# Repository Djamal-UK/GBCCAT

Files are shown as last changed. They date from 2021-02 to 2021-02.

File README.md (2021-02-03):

# GBCCAT
GBCCAT - Gameboy Color Emulator based on GNUBOY,
still in development, used hardware is ESP32 WROVER chip, ST7789 1.3" LCD 240*240px,
loading games from microSD card, emulator has been controlled by PS2 (USB) keyboard.

Image description

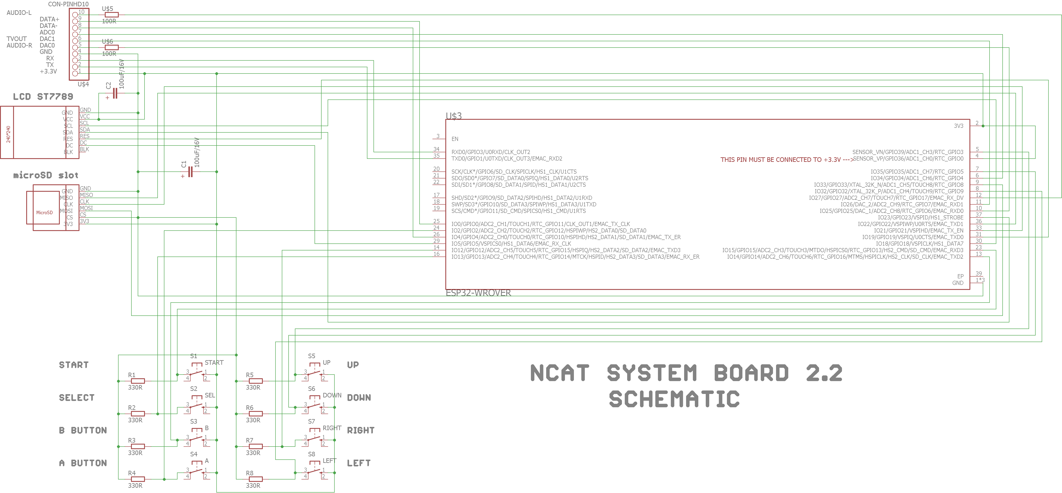
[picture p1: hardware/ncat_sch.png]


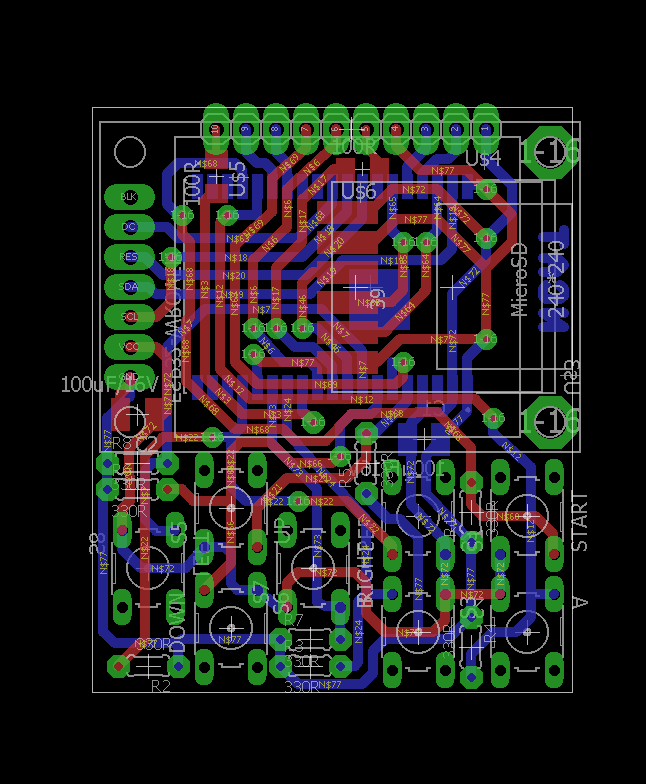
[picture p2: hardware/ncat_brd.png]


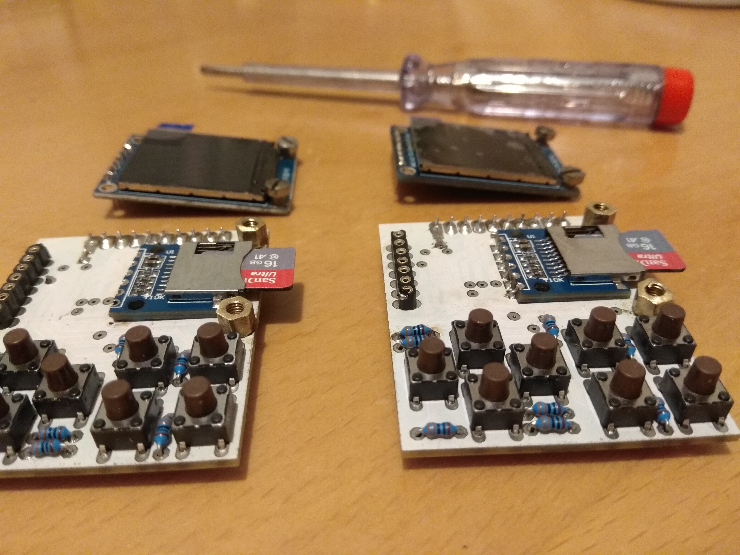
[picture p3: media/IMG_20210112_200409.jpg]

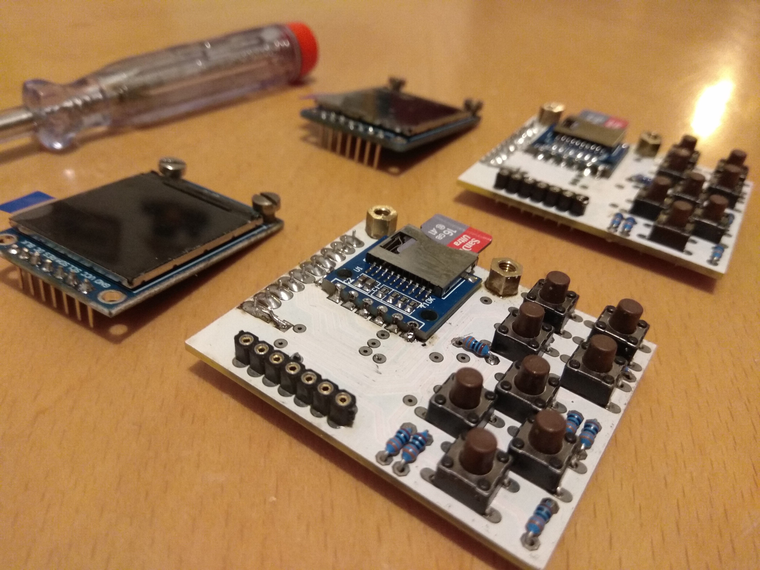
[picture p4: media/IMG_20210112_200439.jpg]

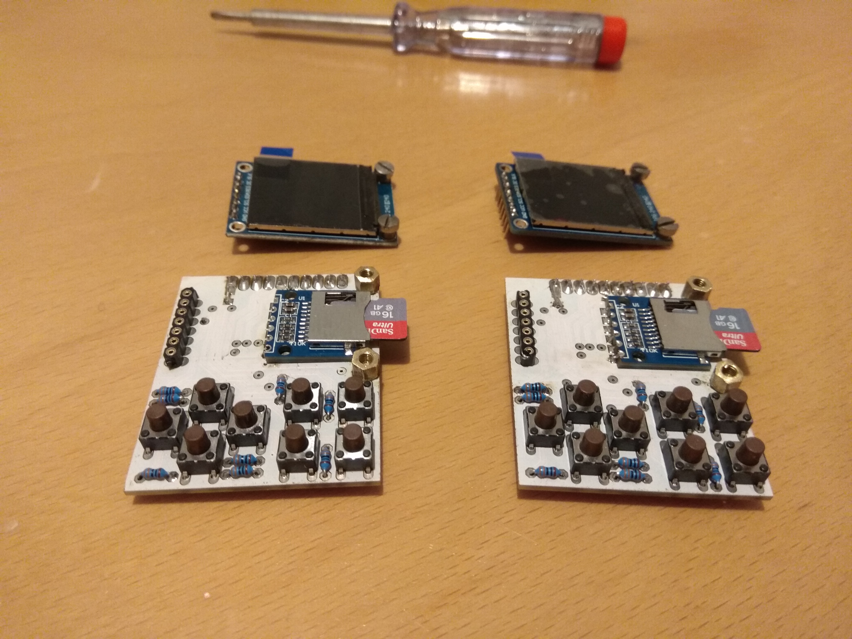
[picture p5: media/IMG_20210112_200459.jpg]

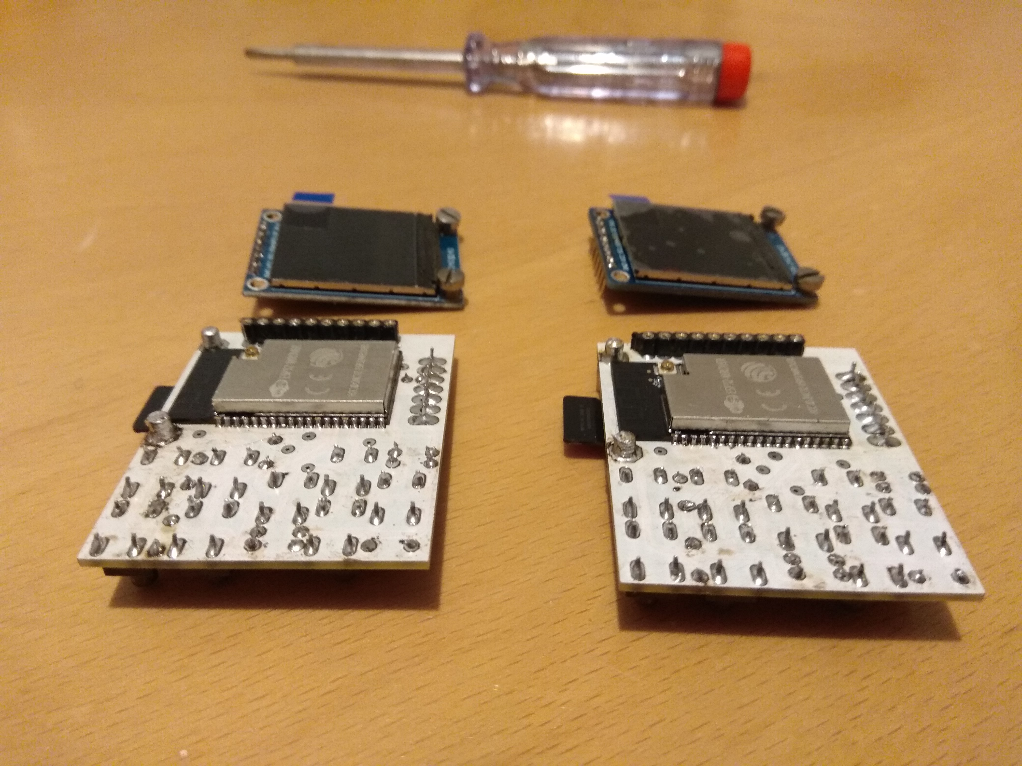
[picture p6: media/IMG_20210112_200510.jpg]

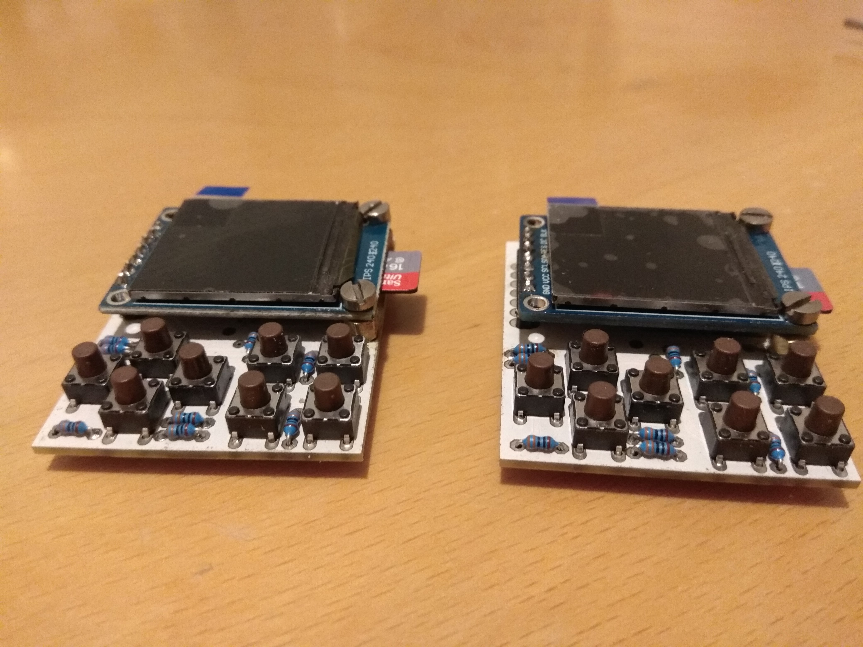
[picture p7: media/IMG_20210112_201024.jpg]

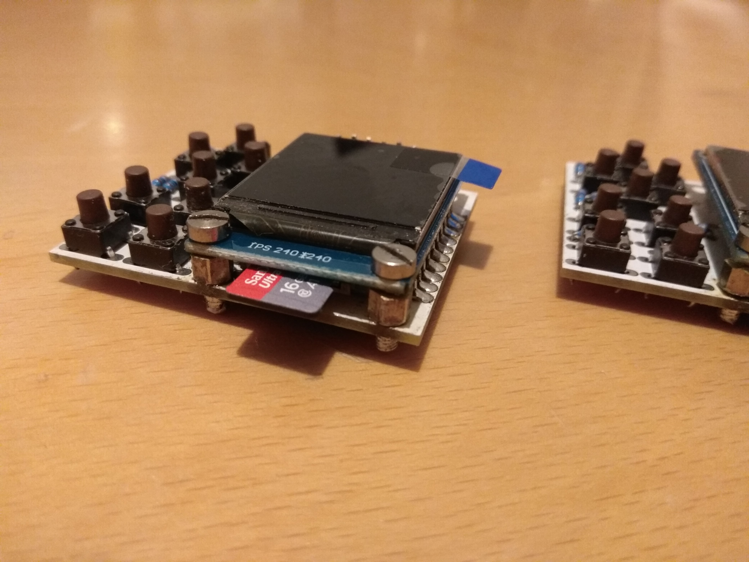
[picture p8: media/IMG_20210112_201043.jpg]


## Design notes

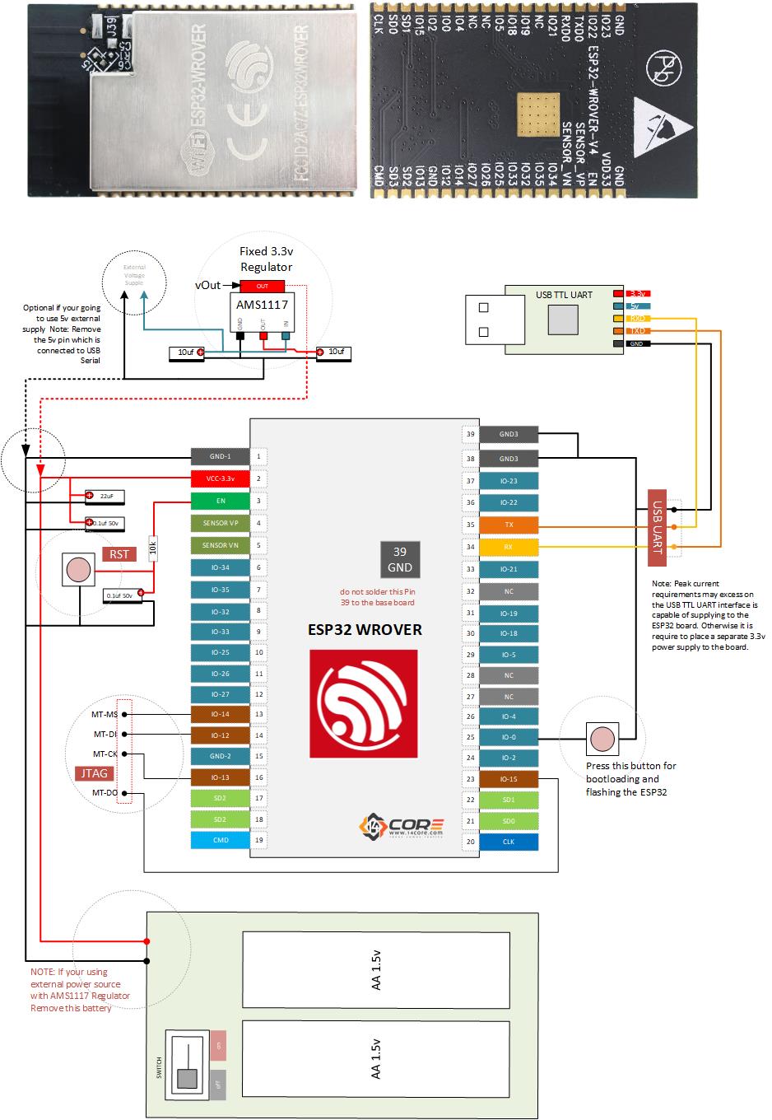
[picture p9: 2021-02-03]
media/Flashing-esp32-wroom-esp32-wrover-flash-download-tool-diagram-schematics.jpg

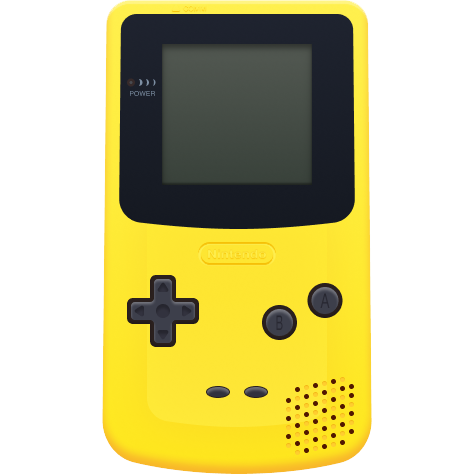
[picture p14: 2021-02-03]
nmcndnhlndv.png

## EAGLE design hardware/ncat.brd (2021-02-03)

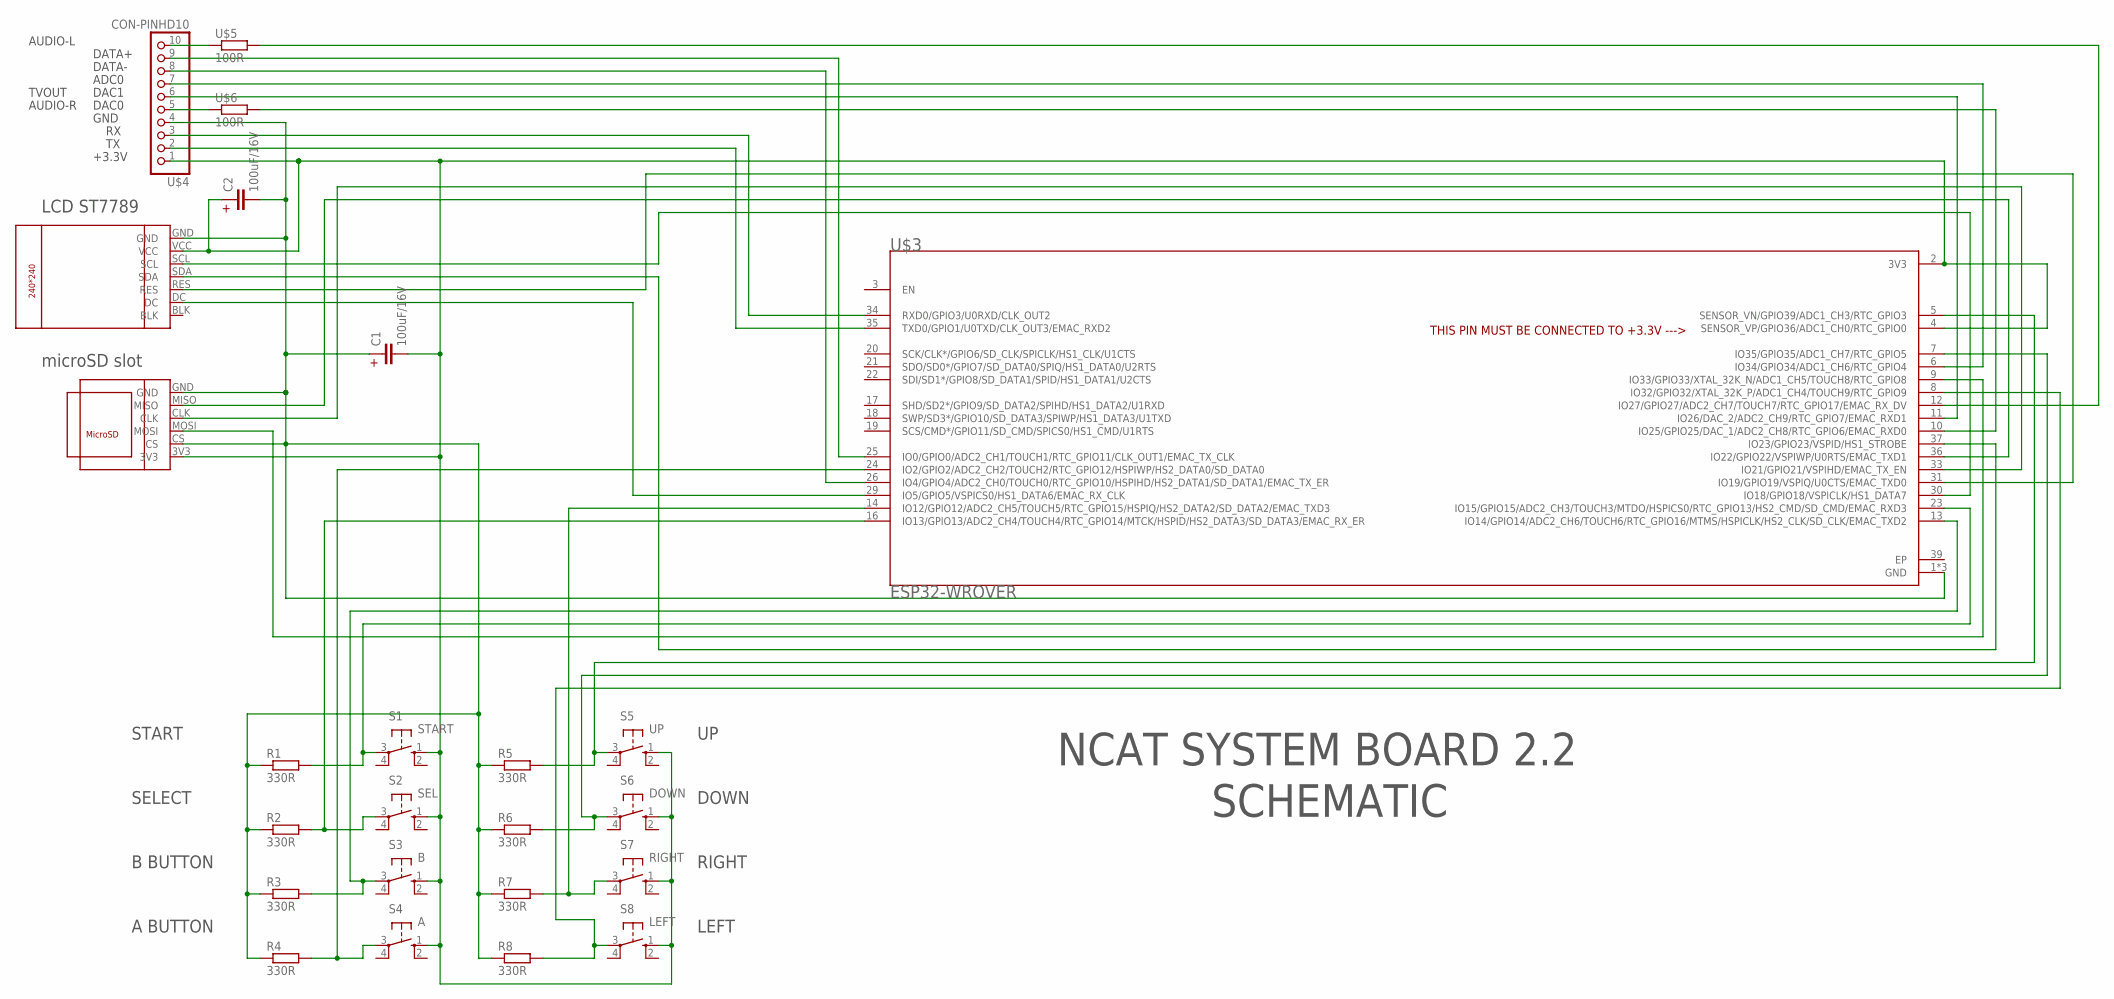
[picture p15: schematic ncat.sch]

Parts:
C1, C2: 100uF/16V; C1210
R1, R2, R3, R4, R5, R6, R7, R8: 330R; R0204/5H
S1: START; B3F-10XX
S2: SEL; B3F-10XX
S3: B; B3F-10XX
S4: A; B3F-10XX
S5: UP; B3F-10XX
S6: DOWN; B3F-10XX
S7: RIGHT; B3F-10XX
S8: LEFT; B3F-10XX
U$1: MICROSD-CARD-MODULESMD; MICROSD-CARD-MODULE-SMD
U$3: ESP32-WROVER; XCVR-ESP32-WROVER
U$4: CON-PINHD10; PIN1X10
U$5, U$6: 100R; R1206/SMD
U$7: LCD-ST7789-1.3INCH

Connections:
EP: U$3.39 (EP)
unnamed: U$3.35 (TXD0/GPIO1/U0TXD/CLK_OUT3/EMAC_RXD2), U$4.2
unnamed: U$3.34 (RXD0/GPIO3/U0RXD/CLK_OUT2), U$4.3
unnamed: U$3.12 (IO27/GPIO27/ADC2_CH7/TOUCH7/RTC_GPIO17/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), U$5.2
unnamed: U$4.5, U$6.1
unnamed: U$4.10, U$5.1
unnamed: U$3.11 (IO26/DAC_2/ADC2_CH9/RTC_GPIO7/EMAC_RXD1), U$4.6
unnamed: R8.2, S8.3, U$3.8 (IO32/GPIO32/XTAL_32K_P/ADC1_CH4/TOUCH9/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)
unnamed: R4.2, S4.3, U$3.24 (IO2/GPIO2/ADC2_CH2/TOUCH2/RTC_GPIO12/HS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)
unnamed: U$3.10 (IO25/GPIO25/DAC_1/ADC2_CH8/RTC_GPIO6/EM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), U$6.2
unnamed: U$3.30 (IO18/GPIO18/VSPICLK/HS1_DATA7), U$7.SCL
unnamed: U$3.37 (IO23/GPIO23/VSPID/HS1_STROBE), U$7.SDA
unnamed: U$3.31 (IO19/GPIO19/VSPIQ/U0CTS/EMAC_TXD0), U$7.RES
unnamed: R5.2, S5.3, U$3.5 (SENSOR_VN/GPIO39/ADC1_CH3/RTC_GPIO3)
unnamed: R2.2, S2.3, U$3.16 (IO13/GPIO13/ADC2_CH4/TOUCH4/RTC_GPIO14/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)
unnamed: R3.2, S3.3, U$3.13 (IO14/GPIO14/ADC2_CH6/TOUCH6/RTC_GPIO16/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)
unnamed: U$1.MOSI, U$3.9 (IO33/GPIO33/XTAL_32K_N/ADC1_CH5/TOUCH8/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)
unnamed: U$3.29 (IO5/GPIO5/VSPICS0/HS1_DATA6/EMAC_RX_CLK), U$7.DC
unnamed: U$1.MISO, U$3.36 (IO22/GPIO22/VSPIWP/U0RTS/EMAC_TXD1)
unnamed: U$1.CLK, U$3.33 (IO21/GPIO21/VSPIHD/EMAC_TX_EN)
unnamed: R6.2, S6.3, U$3.7 (IO35/GPIO35/ADC1_CH7/RTC_GPIO5)
unnamed: R1.2, S1.3, U$3.23 (IO15/GPIO15/ADC2_CH3/TOUCH3/MTDO/HSPICS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)
unnamed: U$3.6 (IO34/GPIO34/ADC1_CH6/RTC_GPIO4), U$4.7
unnamed: U$3.26 (IO4/GPIO4/ADC2_CH0/TOUCH0/RTC_GPIO10/HS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), U$4.8
unnamed: U$3.25 (IO0/GPIO0/ADC2_CH1/TOUCH1/RTC_GPIO11/CL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), U$4.9
unnamed: C1.2, C2.1, S1.1 (S), S2.1 (S), S3.1 (S), S4.1 (S), S5.1 (S), S6.1 (S), S7.1 (S), S8.1 (S), U$1.3V3, U$3.2 (3V3), U$3.4 (SENSOR_VP/GPIO36/ADC1_CH0/RTC_GPIO0), U$4.1, U$7.VCC
unnamed: R7.2, S7.3, U$3.14 (IO12/GPIO12/ADC2_CH5/TOUCH5/RTC_GPIO15/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)
unnamed: C1.1, C2.2, R1.1, R2.1, R3.1, R4.1, R5.1, R6.1, R7.1, R8.1, U$1.CS, U$1.GND, U$3.1 (GND), U$3.15 (GND), U$3.38 (GND), U$4.4, U$7.GND

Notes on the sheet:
LCD ST7789
microSD slot
START
SELECT
A BUTTON
B BUTTON
DOWN
RIGHT
LEFT
GND
DAC1
DAC0
ADC0
DATA+
DATA-
+3.3V
SCHEMATIC
TVOUT
AUDIO-L
AUDIO-R
NCAT SYSTEM BOARD 2.2
THIS PIN MUST BE CONNECTED TO +3.3V --->

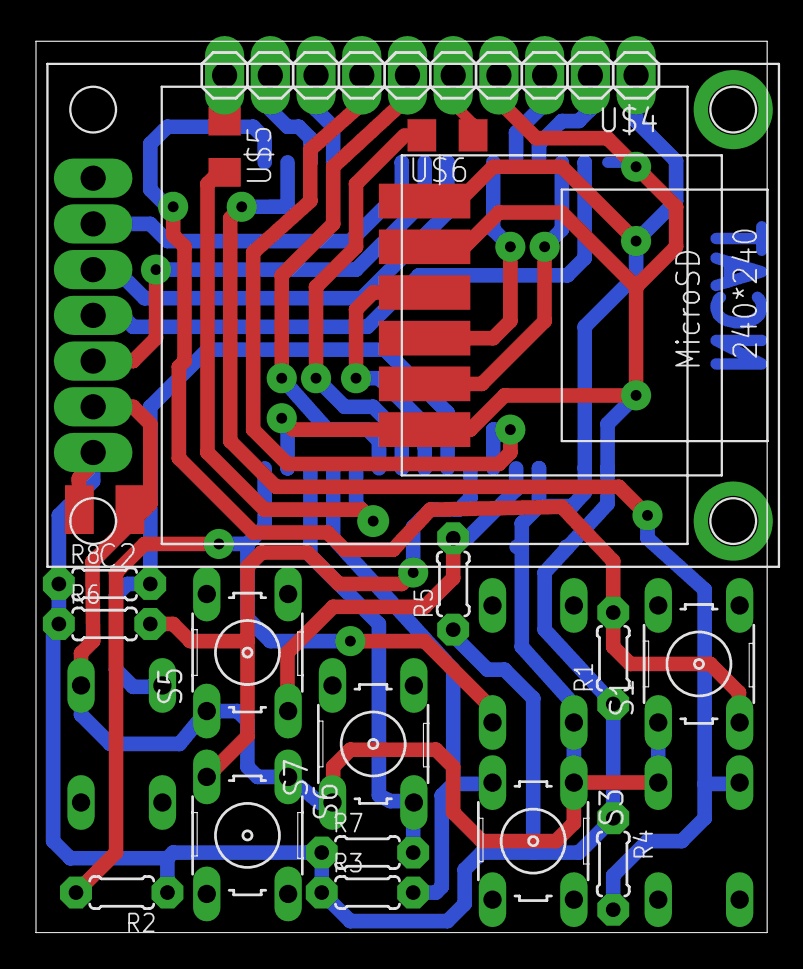
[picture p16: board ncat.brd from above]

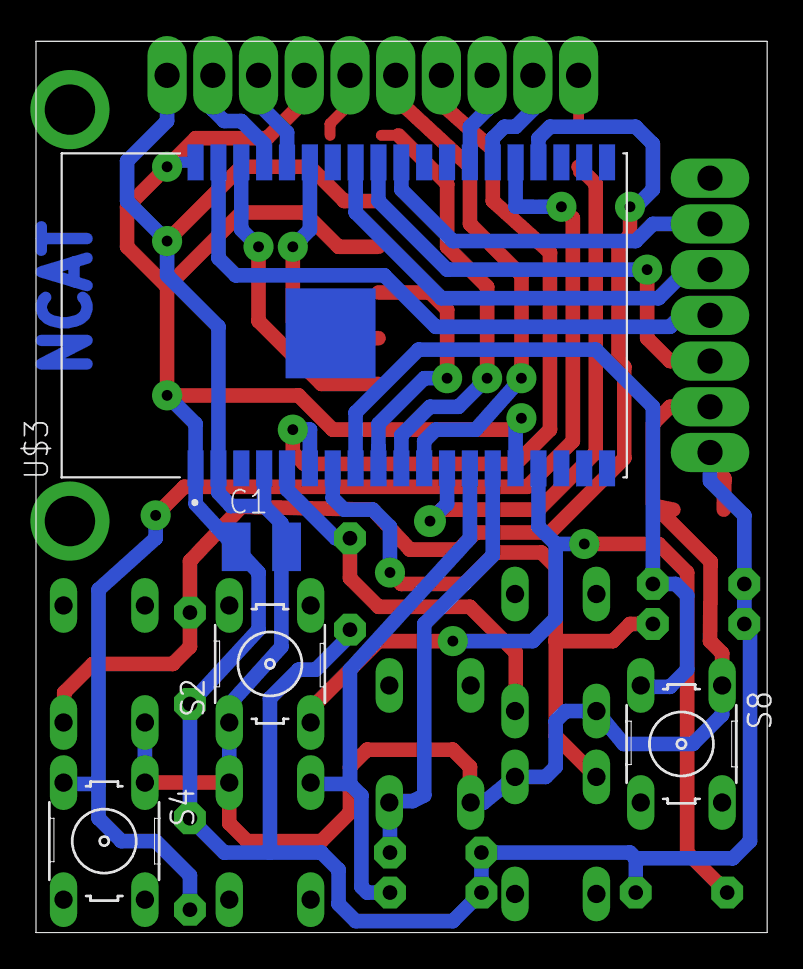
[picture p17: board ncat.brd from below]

Board: 2 copper layers, 40.6 x 49.5 mm, 24 parts (5 on the bottom side), 27 nets.

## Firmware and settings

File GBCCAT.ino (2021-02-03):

#include "loader.h"
#include "mem.h"
#include "rtc.h"
#include "emu.h"
#include "sys.h"

#include "sound.h"

#define INCLUDED_LIBRARIES true //better enable this feature!                           

#define LCD_ENABLED true
#define COMPOSITE_VIDEO_ENABLED true  //Do not disable! it also disable ADC.
#define KEYBOARD_ENABLED true
#define SOUND_ENABLED true
#define BLUETOOTH_ENABLED false //experimental.

#define DEBUG true       //Serial debugging enable.
#define DEBUGEXTRA false //Extra Serial debugging enable.

#define I2S_MODULE_INSTALLED false //we do not use I2S PCM5102A module (= PWM direct output)

//********************************************************************************

//KEY BUTTONS PINS:
#define PIN_UP     39  //SVN
#define PIN_DOWN   35  //IO35
#define PIN_LEFT   32 /// 36  //SVP
#define PIN_RIGHT  12  //TDI => Do not install 330R resistor!!!
#define PIN_A      2   //IO2
#define PIN_B      14  //TMS
#define PIN_START  15  //TDO
#define PIN_SELECT 13  //TCK

///!!! do not forget 1KOHM resistors
#define KEYBOARD_DATA 4  /// ---[ 1K ]--- // -D
#define KEYBOARD_CLK 0   /// ---[ 1K ]--- // +D

//COMPOSITE_VIDEO: - //DAC_GPIO25_CHANNEL or DAC_GPIO26_CHANNEL

#define VIDEO_OUT (DAC_GPIO26_CHANNEL)

//AUDIO DIRECT OUTPUT:
#define CONFIG_LEFT_CHANNEL_GPIO 25
#define CONFIG_RIGHT_CHANNEL_GPIO 27

//AUDIO_i2S:
#define I2S_DOUT (GPIO_NUM_25) //DIN
#define I2S_BCLK (GPIO_NUM_27) //BCK
#define I2S_LRC  (GPIO_NUM_32) //LCK
#define I2S_DI_IO -1           //Not Used

//LCD_ST7789:
#define TFT_CS   -1  // define chip select pin
#define TFT_DC    5  // define data/command pin
#define TFT_RST  19  
#define TFT_MOSI 23  // Data out (SDA) //better not change
#define TFT_SCLK 18  // Clock out (SCL) //better not change

//micro_SD_Card: //GPIO16 and GPIO17 can not use on WROVER
#define SOFTSD_MOSI_PIN 33
#define SOFTSD_MISO_PIN 22
#define SOFTSD_SCK_PIN  21
#define SD_CS_PIN -1     //not used

//Oscilloscope INPUT:
#define ADC_CHANNEL   ADC1_CHANNEL_6 // GPIO34

//********************************************************************************
#include "pwm_audio.h"

pwm_audio_config_t pac;
//********************************************************************************

//********************************************************************************
//MAIN LIBRARIES:

///#include "esp_wifi.h" 
///#include "esp_bt.h"

#include <esp_task_wdt.h>
#include "esp_types.h"
#include "esp_heap_caps.h"
#include "esp_attr.h"
#include "esp_intr_alloc.h"
#include "esp_err.h"
#include "soc/gpio_reg.h"
#include "soc/rtc.h"
#include "soc/soc.h"
#include "soc/i2s_struct.h"
#include "soc/i2s_reg.h"
#include "soc/ledc_struct.h"
#include "soc/rtc_io_reg.h"
#include "soc/io_mux_reg.h"
#include "rom/gpio.h"
#include "rom/lldesc.h"
#include "driver/periph_ctrl.h"
#include "driver/dac.h"
#include "driver/gpio.h"
#if SOUND_ENABLED
#include "driver/i2s.h"
#endif

//LIBRARIES:
///#include "Arduino.h"

//********************************************************************************
//********************************************************************************


//********************************************************************************
//VARIABLES:

//Allocated MEMORY variables:
uint8_t* SCREENMEMORY[256 + 1];  //256*256 bytes + 256 offset
uint16_t SCREENBUFFER[256];  //512 bytes

uint32_t PSRAMSIZE = 0;
uint8_t* PSRAM;


//COMPOSITE_VIDEO_OUT
#if COMPOSITE_VIDEO_ENABLED
#include "src/compositevideo/video.h"
#endif

//AUDIO_i2S:
//********************************************************************************
#if INCLUDED_LIBRARIES

//MODIFIED INCLUDED_LIBRARIES in "/src/" folder

//LCD_ST7789:
#include <SPI.h>
#include "src/Adafruit-GFX-Library/Adafruit_GFX.h"    // Core graphics library
#include "src/Adafruit-ST7735-Library/Adafruit_ST7789.h"    // Core graphics library

//micro_SD_Card:
#include "src/sdfat-beta/src/SdFat.h" // Use SDFAT-beta...

//AUDIO_i2S:
#if SOUND_ENABLED
///#include "driver/i2s.h"
#endif

//player LIBs
#include "src/ESP32-audioI2S/src/Audio.h" // Use SDFAT-beta...

//--------------------------------------------------------------------------------
///#include "arduinoFFT.h" // Standard Arduino FFT library
#include "src/arduinoFFT/src/arduinoFFT.h" // Standard Arduino FFT library

//********************************************************************************
#else
//********************************************************************************

//!!! or use MODIFIED LIBRARIES in "Arduino/libraries/" folder (need copy from /LIBRARIES/)

//LCD_ST7789:
#include <SPI.h>
#include <Adafruit_GFX.h>    // Core graphics library
#include <Adafruit_ST7789.h> // Hardware-specific library for ST7789

//micro_SD_Card:
#include <SdFat.h> // Use SDFAT-beta...

//player LIBs
///#include "Audio.h" //ESP32-audioI2S

#include "arduinoFFT.h" // Standard Arduino FFT library
//********************************************************************************
#endif

//********************************************************************************
//SETUP:

//USE SDFAT BETA!
SoftSpiDriver<SOFTSD_MISO_PIN, SOFTSD_MOSI_PIN, SOFTSD_SCK_PIN> softSpi;
#define SD_CONFIG SdSpiConfig(-1, DEDICATED_SPI, SD_SCK_MHZ(0), &softSpi)
SdFat SD;
File fp;

//LCD_ST7789
#define ST7789_DRIVER     // Configure all registers
#define TFT_WIDTH  240
#define TFT_HEIGHT 240
#define LOAD_GLCD   // Font 1. Original Adafruit 8 pixel font needs ~1820 bytes in FLASH
#define LOAD_FONT2  // Font 2. Small 16 pixel high font, needs ~3534 bytes in FLASH, 96 characters
#define LOAD_FONT4  // Font 4. Medium 26 pixel high font, needs ~5848 bytes in FLASH, 96 characters
Adafruit_ST7789 tft = Adafruit_ST7789(TFT_CS, TFT_DC, TFT_RST);

//--------------------------------------------------------------------------------
//SPI FLASH MEMORY ACCESS:
#include "esp_spi_flash.h"

#define SPI_FLASH_ADDRESS 0x00300000 //0x00300000 working (empty flash area)
#define SPI_FLASH_SECTOR_SIZE 0x1000 //4kB = better not change

uint32_t FILE_ROM_SIZE = 0;
uint32_t FLASH_ROM_SIZE = 0;

//constant data pointer for direct access
const void *ROM;

spi_flash_mmap_handle_t handle1;

uint8_t flashdata[4096] = {0}; //4kB buffer

//--------------------------------------------------------------------------------
//DRAM MEMORY ACCESS:
//--------------------------------------------------------------------------------

char* ROMFILENAME; //ROM load File name
///unsigned char *rom = 0; //Actual ROM pointer

//********************************************************************************


//--------------------------------------------------------------------------------
//NES PALETTES 32bit & 16bit:

const uint32_t nes_32bit[64] = { //4colors Green-Yellow-Red-Blue
  0x2D253469, 0x000000D9, 0x000000A1, 0x0F111CA1, 0x001F3F70, 0x0024491C, 0x06264900, 0x061F3B00,
  0x12162300, 0x2D0B0000, 0x27090000, 0x21080000, 0x1806004D, 0x14141414, 0x14141414, 0x14141414,
  0x453950A1, 0x2D0B00D9, 0x210800D9, 0x181C2DD9, 0x002F5EAF, 0x0031624D, 0x153B6C00, 0x2139620E,
  0x2D304900, 0x45110000, 0x3F0F0000, 0x3F0F0038, 0x330C0077, 0x14141414, 0x14141414, 0x14141414,
  0x5D4D6CD9, 0x451D18D9, 0x33232DD9, 0x2D2C42D9, 0x2D416CD9, 0x213E6C85, 0x2D416C4D, 0x3C456C38,
  0x45476C00, 0x5D3F5015, 0x51272646, 0x5D2A2685, 0x571500BD, 0x2D253469, 0x14141414, 0x14141414,
  0x5D4D6CD9, 0x543846D9, 0x453950D9, 0x45405ED9, 0x45476CD9, 0x3C456CA8, 0x4E48699A, 0x544B6C93,
  0x514A6C69, 0x5D465E69, 0x5D3F50A1, 0x5D3F50BD, 0x5D1700D9, 0x514A6CD9, 0x14141414, 0x14141414,
};

const uint16_t nes_16bit[64] = {
  0x7BEF, 0x001F, 0x0017, 0x4157, 0x9010, 0xA804, 0xA880, 0x88A0,
  0x5180, 0x03C0, 0x0340, 0x02C0, 0x020B, 0x0000, 0x0000, 0x0000,
  0xBDF7, 0x03DF, 0x02DF, 0x6A3F, 0xD819, 0xE00B, 0xF9C0, 0xE2E2,
  0xABE0, 0x05C0, 0x0540, 0x0548, 0x0451, 0x0000, 0x0000, 0x0000,
  0xFFDF, 0x3DFF, 0x6C5F, 0x9BDF, 0xFBDF, 0xFAD3, 0xFBCB, 0xFD08,
  0xFDC0, 0xBFC3, 0x5ECA, 0x5FD3, 0x075B, 0x7BCF, 0x0000, 0x0000,
  0xFFFF, 0xA73F, 0xBDDF, 0xDDDF, 0xFDDF, 0xFD38, 0xF696, 0xFF15,
  0xFECF, 0xDFCF, 0xBFD7, 0xBFDB, 0x07FF, 0xFEDF, 0x0000, 0x0000,
};

const uint16_t gbc_16bit[64] = {
0x0,0x10,0x20,0x30,0x4000,0x4010,0x4020,0x4030,
0x8000,0x8010,0x8020,0x8030,0xC000,0xC010,0xC020,0xC030,
0x200,0x210,0x220,0x230,0x4200,0x4210,0x4220,0x4230,
0x8200,0x8210,0x8220,0x8230,0xC200,0xC210,0xC220,0xC230,
0x400,0x410,0x420,0x430,0x4400,0x4410,0x4420,0x4430,
0x8400,0x8410,0x8420,0x8430,0xC400,0xC410,0xC420,0xC430,
0x600,0x610,0x620,0x630,0x4600,0x4610,0x4620,0x4630,
0x8600,0x8610,0x8620,0x8630,0xC600,0xC610,0xC620,0xC630,
};

const uint32_t gbc_32bit[64] = {
0b00001111000011110000111100001111,
0x40,0x80,0xC0,0x4000,0x4040,0x4080,0x40C0,
0x408000,0x408040,0x408080,0x4080C0,0x40C000,0x40C040,0x40C080,0x40C0C0,
0x40000000,0x40000040,0x40000080,0x400000C0,0x40404000,0x40404040,0x40404080,0x404040C0,
0x40408000,0x40408040,0x40408080,0x404080C0,0x4080C000,0x4080C040,0x4080C080,0x4080C0C0,
0x80400000,0x80400040,0x80400080,0x804000C0,0x80404000,0x80404040,0x80404080,0x804040C0,
0x80808000,0x80808040,0x80808080,0x808080C0,0x8080C000,0x8080C040,0x8080C080,0x8080C0C0,
0xC0400000,0xC0400040,0xC0400080,0xC04000C0,0xC0804000,0xC0804040,0xC0804080,0xC08040C0,
0xC0808000,0xC0808040,0xC0808080,0xC08080C0,0x80C08000,0x80C08040,0x80C08080,0x80C080C0,
};

//--------------------------------------------------------------------------------
//for player...
bool PLAYING = false;
bool PAUSED = false;

//===============================================================================
//===============================================================================
//===============================================================================
//INPUT SYSTEM:
uint8_t JOY_UP = 0;
uint8_t JOY_DOWN = 0;
uint8_t JOY_LEFT = 0;
uint8_t JOY_RIGHT = 0;
uint8_t JOY_CROSS = 0;
uint8_t JOY_SQUARE = 0;
uint8_t JOY_CIRCLE = 0;
uint8_t JOY_TRIANGLE = 0;
uint8_t JOY_SHARE = 0; //(START)
uint8_t JOY_OPTIONS = 0; //(SELECT)

//================================================================================
bool buttonchange=false;
uint32_t badge_input_button_state = 0; 
//================================================================================

//--------------------------------------------------------------------------------
uint8_t scancode = 0;
boolean keyup = false;
byte keymap[256];
//--------------------------------------------------------------------------------
IRAM_ATTR void USB_KEYBOARD() {
#if KEYBOARD_ENABLED
  if (keymap[0x75] == 0) {
    JOY_UP = 1;
  } else JOY_UP = 0;
  if (keymap[0x72] == 0) {
    JOY_DOWN = 1;
  } else JOY_DOWN = 0;
  if (keymap[0x6B] == 0) {
    JOY_LEFT = 1;
  } else JOY_LEFT = 0;
  if (keymap[0x74] == 0) {
    JOY_RIGHT = 1;
  } else JOY_RIGHT = 0;

  if (keymap[0x11] == 0 || keymap[0x1A] == 0) JOY_CROSS = 1; //ALT or X
  else JOY_CROSS = 0;
  if (keymap[0x14] == 0 || keymap[0x22] == 0) JOY_SQUARE = 1; //CTRL or Z
  else JOY_SQUARE = 0;
  if (keymap[0x5A] == 0) JOY_SHARE = 1;
  else JOY_SHARE = 0;
  if (keymap[0x66] == 0) JOY_OPTIONS = 1;
  else JOY_OPTIONS = 0;

  if (keymap[0x76] == 0) {
    JOY_SHARE = 1;
    JOY_OPTIONS = 1;
  } else if (JOY_SHARE == 1 && JOY_OPTIONS == 1 ) {
    JOY_SHARE = 0;
    JOY_OPTIONS = 0;
  }

  if (DEBUGEXTRA) {
    if (JOY_UP) Serial.print("UP.");
    if (JOY_DOWN) Serial.print("DOWN.");
    if (JOY_LEFT) Serial.print("LEFT.");
    if (JOY_RIGHT) Serial.print("RIGHT.");
    if (JOY_SHARE) Serial.print("START.");
    if (JOY_OPTIONS) Serial.print("SELECT.");
    if (JOY_CROSS) Serial.print("A.");
    if (JOY_SQUARE) Serial.print("B.");
    Serial.println();
  }



if (JOY_CROSS==1) badge_input_button_state |= 1 << 6;
else badge_input_button_state &= 0b11111111111111111111111110111111;  

if (JOY_SQUARE==1) badge_input_button_state |= 1 << 7;
else badge_input_button_state &= 0b11111111111111111111111101111111;
 
if (JOY_SHARE==1) badge_input_button_state |= 1 << 9;
else badge_input_button_state &= 0b11111111111111111111110111111111;

if (JOY_OPTIONS==1)badge_input_button_state |= 1 << 8;
else badge_input_button_state &= 0b11111111111111111111111011111111;  

if (JOY_UP==1) badge_input_button_state |= 1 << 1;
else badge_input_button_state &= 0b11111111111111111111111111111101;  

if (JOY_DOWN==1) badge_input_button_state |= 1 << 2;
else badge_input_button_state &= 0b11111111111111111111111111111011;  

if (JOY_LEFT==1) badge_input_button_state |= 1 << 3;
else badge_input_button_state &= 0b11111111111111111111111111110111;  

if (JOY_RIGHT==1) badge_input_button_state |= 1 << 4;
else badge_input_button_state &= 0b11111111111111111111111111101111;

  buttonchange=true;



  
#endif
}
//--------------------------------------------------------------------------------
void IRAM_ATTR kb_interruptHandler(void) {
#if KEYBOARD_ENABLED
  static uint8_t bitcount = 0;
  uint8_t val;

  int clock = digitalRead(KEYBOARD_CLK);
  if (clock == 0) {
    return;
  }

  val = digitalRead(KEYBOARD_DATA);
  if (DEBUGEXTRA) Serial.print(".");
  if (DEBUGEXTRA) Serial.print(val);

  bitcount++;

  if (bitcount > 1 && bitcount < 10) { //8bits
    scancode |= ((val & 1) << (bitcount - 2));
  }

  if (bitcount > 10) {
    if (keyup == true) {
      keymap[scancode] = 1;

      if (DEBUGEXTRA) {
        Serial.print(" {");
        Serial.print(scancode, HEX);
        Serial.print("} ");
      }
      keyup = false;
    } else {
      keymap[scancode] = 0;
    }

    if (scancode  == 0xF0  ) {
      keyup = true;
    } else {
      keyup = false;
    }

    if (DEBUGEXTRA) {
      Serial.print("[");
      Serial.print(scancode, HEX);
      Serial.println("]");
    }

    USB_KEYBOARD();

    bitcount = 0;
    scancode = 0;
  }
#endif
}
//--------------------------------------------------------------------------------
void kb_begin() {
#if KEYBOARD_ENABLED
  pinMode(KEYBOARD_DATA, INPUT_PULLUP);
  pinMode(KEYBOARD_CLK, INPUT_PULLUP);
  digitalWrite(KEYBOARD_DATA, true);
  digitalWrite(KEYBOARD_CLK, true);
  attachInterrupt(digitalPinToInterrupt(KEYBOARD_CLK), kb_interruptHandler, RISING);
  memset(keymap, 1, sizeof(keymap));
#endif
}
//********************************************************************************
//================================================================================
//================================================================================
void IRAM_ATTR JOY_A_Handler(void) {
   if (digitalRead(PIN_A)==1) JOY_CROSS=1;
   else JOY_CROSS=0;
   buttonchange=true;
   if (JOY_CROSS==1) badge_input_button_state |= 1 << 6;
   else badge_input_button_state &= 0b11111111111111111111111110111111;  
   return;  
}  
//--------------------------------------------------------------------------------
void IRAM_ATTR JOY_B_Handler(void) {
   if (digitalRead(PIN_B)==1) JOY_SQUARE=1;
   else JOY_SQUARE=0;
   buttonchange=true;
   if (JOY_SQUARE==1) badge_input_button_state |= 1 << 7;
   else badge_input_button_state &= 0b11111111111111111111111101111111;
   return;  
}  
//--------------------------------------------------------------------------------
void IRAM_ATTR JOY_START_Handler(void) {
   if (digitalRead(PIN_START)==1) JOY_SHARE=1;
   else JOY_SHARE=0;
   buttonchange=true;
   if (JOY_SHARE==1) badge_input_button_state |= 1 << 9;
   else badge_input_button_state &= 0b11111111111111111111110111111111;
   return;  
}  
//--------------------------------------------------------------------------------
void IRAM_ATTR JOY_SELECT_Handler(void) {
   if (digitalRead(PIN_SELECT)==1) JOY_OPTIONS=1;
   else JOY_OPTIONS=0;
   buttonchange=true;
   if (JOY_OPTIONS==1) badge_input_button_state |= 1 << 8;
   else badge_input_button_state &= 0b11111111111111111111111011111111;  
   return;  
}  
//--------------------------------------------------------------------------------
void IRAM_ATTR JOY_UP_Handler(void) {
   if (digitalRead(PIN_UP)==1) JOY_UP=1;
   else JOY_UP=0;
   buttonchange=true;
   if (JOY_UP==1) badge_input_button_state |= 1 << 1;
   else badge_input_button_state &= 0b11111111111111111111111111111101;  
   return;  
}  
//--------------------------------------------------------------------------------
void IRAM_ATTR JOY_DOWN_Handler(void) {
   if (digitalRead(PIN_DOWN)==1) JOY_DOWN=1;
   else JOY_DOWN=0;
   buttonchange=true;
   if (JOY_DOWN==1) badge_input_button_state |= 1 << 2;
   else badge_input_button_state &= 0b11111111111111111111111111111011;  
   return;  
}  
//--------------------------------------------------------------------------------
void IRAM_ATTR JOY_LEFT_Handler(void) {
   if (digitalRead(PIN_LEFT)==1) JOY_LEFT=1;
   else JOY_LEFT=0;
   buttonchange=true;
   if (JOY_LEFT==1) badge_input_button_state |= 1 << 3;
   else badge_input_button_state &= 0b11111111111111111111111111110111;  
   return;  
}  
//--------------------------------------------------------------------------------
void IRAM_ATTR JOY_RIGHT_Handler(void) {
   if (digitalRead(PIN_RIGHT)==1) JOY_RIGHT=1;
   else JOY_RIGHT=0;
   buttonchange=true;
   if (JOY_RIGHT==1) badge_input_button_state |= 1 << 4;
   else badge_input_button_state &= 0b11111111111111111111111111101111;  
   return;  
}  
//================================================================================




#include <esp_task_wdt.h>

/*
extern "C" {
extern const unsigned char game_rom[];
extern const unsigned int game_rom_len;
extern void burnin();
};
*/


//===============================================================================
//INCLUDES:

//MAIN FONT
#include "Retro8x16.c" //used font...

//MENU ICON
///#include "icons.c" //used font...

//===============================================================================
//===============================================================================
//===============================================================================
//VIDEO SYSTEM:
QueueHandle_t vidQueue;

//VIDEO_SETUP
#define DEFAULT_WIDTH 240
#define DEFAULT_HEIGHT 240
//--------------------------------------------------------------------------------
//BUFFER TEXT DRAW FUNCTIONS
//--------------------------------------------------------------------------------
extern SemaphoreHandle_t fb_mutex;
//--------------------------------------------------------------------------------


void screenmemory_fillscreen(uint8_t COLOR) {
  for (uint16_t Ypos = 0; Ypos < DEFAULT_HEIGHT; Ypos++)
    for (uint16_t Xpos = 0; Xpos < DEFAULT_WIDTH; Xpos++) {
      SCREENMEMORY[Ypos][Xpos] = COLOR;
    }
///  if (LCD_ENABLED) xQueueSend(vidQueue, &SCREENMEMORY, 0); //refresh LCD
xSemaphoreGive(fb_mutex);
}
//--------------------------------------------------------------------------------
void screenmemory_drawpixel(uint16_t X, uint16_t Y, uint8_t COLOR) {
  if (Y < DEFAULT_HEIGHT && X < DEFAULT_WIDTH) SCREENMEMORY[Y][X] = COLOR;
}
//--------------------------------------------------------------------------------
void screenmemory_line(int startx, int starty, int endx, int endy, uint8_t color) {
  int t, distance;
  int xerr = 0, yerr = 0, delta_x, delta_y;
  int incx, incy;
  // compute the distances in both directions
  delta_x = endx - startx;
  delta_y = endy - starty;
  // Compute the direction of the increment,
  //   an increment of 0 means either a horizontal or vertical
  //   line.
  if (delta_x > 0) incx = 1;
  else if (delta_x == 0) incx = 0;
  else incx = -1;

  if (delta_y > 0) incy = 1;
  else if (delta_y == 0) incy = 0;
  else incy = -1;

  // determine which distance is greater
  delta_x = abs(delta_x);
  delta_y = abs(delta_y);
  if (delta_x > delta_y) distance = delta_x;
  else distance = delta_y;

  // draw the line
  for (t = 0; t <= distance + 1; t++) {
    screenmemory_drawpixel(startx, starty, color);

    xerr += delta_x;
    yerr += delta_y;
    if (xerr > distance) {
      xerr -= distance;
      startx += incx;
    }
    if (yerr > distance) {
      yerr -= distance;
      starty += incy;
    }
  }
}
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
void loop()
{
DEFAULTPAL=0;
GBC_EXIT=0;

   screenmemory_fillscreen(63); //black color

   Serial.println("GBC_POWER: ##################");

   sprintf(MAINPATH, "/GBC/"); ///must be malloc(256);

   for (uint16_t tmp = 0; tmp < MAXFILES; tmp++) filename[tmp] = (char*)calloc(MAXFILENAME_LENGTH, sizeof(char));

      GBCBrowse(MAINPATH);
      delay(300);

      for (uint16_t tmp = 0; tmp < MAXFILES; tmp++) free(filename[tmp]);

///      if (EXIT) {
///        return; //return from GBCBrowse();
///      }

      screenmemory_fillscreen(63); //black color

      if (DEBUG) Serial.print("SELECTED GBC: ");
      if (DEBUG) Serial.println(MAINPATH);

//--------------------------------------------------------------------------------
//--------------------------------------------------------------------------------


///  vid_init();

//----------------------------------------
   uint32_t len;
///   game_rom=load_file("smb.gbc",&len);
   game_rom=load_file(MAINPATH,&len);

   
   game_rom_len=len;
//----------------------------------------

DEFAULTPAL=1;

   // setup the ROM image
   Serial.println("loading rom");
   rom_load(game_rom, game_rom_len);
   Serial.println("loaded!");

  // startup the emulator
   emu_reset();

   Serial.println("Starting emulator");
   emu_run();

   Serial.println("Terminated emulator");
   loader_unload();




}

int sys_elapsed(uint32_t * prev) {
   uint32_t now = sys_micros();
   uint32_t delta = now - *prev;
   *prev = now;
   //printf("elapsed: %d\n", delta);
   return delta;
}

void sys_sleep(int us) {
   if (us < 0) return;
   //printf("usleep(%d)\n", us);
   int start = sys_micros();
   while(sys_micros() - start < us) {
      doevents();
      delayMicroseconds(100);
   }
}

unsigned long sys_micros() {
  return micros();
}

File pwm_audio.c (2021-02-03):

// Copyright 2020 Espressif Systems (Shanghai) PTE LTD
//
// Licensed under the Apache License, Version 2.0 (the "License");
// you may not use this file except in compliance with the License.
// You may obtain a copy of the License at
//
//     http://www.apache.org/licenses/LICENSE-2.0
//
// Unless required by applicable law or agreed to in writing, software
// distributed under the License is distributed on an "AS IS" BASIS,
// WITHOUT WARRANTIES OR CONDITIONS OF ANY KIND, either express or implied.
// See the License for the specific language governing permissions and
// limitations under the License.


#include <stdio.h>
#include <string.h>
#include "freertos/FreeRTOS.h"
#include "freertos/semphr.h"
#include "freertos/task.h"
#include "driver/ledc.h"
#include "esp_err.h"
#include "esp_timer.h"
#include "esp_log.h"
#include "esp_heap_caps.h"
#include "driver/timer.h"
#include "soc/timer_group_struct.h"
#include "soc/ledc_struct.h"
#include "soc/ledc_reg.h"
// #include "hal/gpio_ll.h"
// #include "soc/timer_group_caps.h"
#include "pwm_audio.h"
#include "sdkconfig.h"

#define CONFIG_IDF_TARGET_ESP32

#ifndef CONFIG_IDF_TARGET_ESP32S2
#ifndef CONFIG_IDF_TARGET_ESP32
#error No defined idf target esp32 or esp32s2
#endif
#endif


static const char *TAG = "pwm_audio";

#define PWM_AUDIO_CHECK(a, str, ret_val)                          \
    if (!(a))                                                     \
    {                                                             \
        ESP_LOGE(TAG, "%s(%d): %s", __FUNCTION__, __LINE__, str); \
        return (ret_val);                                         \
    }

static const char *PWM_AUDIO_PARAM_ADDR_ERROR = "PWM AUDIO PARAM ADDR ERROR";
static const char *PWM_AUDIO_FRAMERATE_ERROR  = "PWM AUDIO FRAMERATE ERROR";
static const char *PWM_AUDIO_STATUS_ERROR     = "PWM AUDIO STATUS ERROR";
static const char *PWM_AUDIO_TG_NUM_ERROR     = "PWM AUDIO TIMER GROUP NUMBER ERROR";
static const char *PWM_AUDIO_TIMER_NUM_ERROR  = "PWM AUDIO TIMER NUMBER ERROR";
static const char *PWM_AUDIO_ALLOC_ERROR      = "PWM AUDIO ALLOC ERROR";
static const char *PWM_AUDIO_RESOLUTION_ERROR = "PWM AUDIO RESOLUTION ERROR";

#define BUFFER_MIN_SIZE     (256UL)
#define SAMPLE_RATE_MAX     (48000)
#define SAMPLE_RATE_MIN     (8000)
#define CHANNEL_LEFT_INDEX  (0)
#define CHANNEL_RIGHT_INDEX (1)
#define CHANNEL_LEFT_MASK   (0x01)
#define CHANNEL_RIGHT_MASK  (0x02)
#define VOLUME_0DB          (1)

/**
 * Debug Configuration 
 **/
#define ISR_DEBUG 0  /**< INDEBUG SWITCH */
#define ISR_DEBUG_IO_MASK 0x8000

typedef struct {
    char *buf;                         /**< Original pointer */
    uint32_t volatile head;            /**< ending pointer */
    uint32_t volatile tail;            /**< Read pointer */
    uint32_t size;                     /**< Buffer size */
    uint32_t is_give;                  /**< semaphore give flag */
    SemaphoreHandle_t semaphore_rb;    /**< Semaphore for ringbuffer */

} ringBuf;
typedef ringBuf *ringbuf_handle_t;

typedef struct {
    pwm_audio_config_t    config;                          /**< pwm audio config struct */
    ledc_channel_config_t ledc_channel[PWM_AUDIO_CH_MAX];  /**< ledc channel config */
    ledc_timer_config_t   ledc_timer;                      /**< ledc timer config  */
    timg_dev_t            *timg_dev;                       /**< timer group register pointer */
    ringbuf_handle_t      ringbuf;                         /**< audio ringbuffer pointer */
    uint32_t              channel_mask;                    /**< channel gpio mask */
    uint32_t              channel_set_num;                 /**< channel audio set number */
    int32_t               framerate;                       /*!< frame rates in Hz */
    int32_t               bits_per_sample;                 /*!< bits per sample (8, 16, 32) */
    int32_t               volume;                          /*!< the volume(-VOLUME_0DB ~ VOLUME_0DB) */

    pwm_audio_status_t status;
} pwm_audio_handle;
typedef pwm_audio_handle *pwm_audio_handle_t;

/**< ledc some register pointer */
static volatile uint32_t *g_ledc_left_conf0_val  = NULL;
static volatile uint32_t *g_ledc_left_conf1_val  = NULL;
static volatile uint32_t *g_ledc_left_duty_val   = NULL;
static volatile uint32_t *g_ledc_right_conf0_val = NULL;
static volatile uint32_t *g_ledc_right_conf1_val = NULL;
static volatile uint32_t *g_ledc_right_duty_val  = NULL;

/**< pwm audio handle pointer */
static pwm_audio_handle_t g_pwm_audio_handle = NULL;

static portMUX_TYPE timer_spinlock = portMUX_INITIALIZER_UNLOCKED;

/**
 * Ringbuffer for pwm audio
 */
static esp_err_t rb_destroy(ringbuf_handle_t rb)
{
    if (rb == NULL) {
        return ESP_ERR_INVALID_ARG;
    }

    if (rb->buf) {
        heap_caps_free(rb->buf);
    }

    if (rb->semaphore_rb) {
        vSemaphoreDelete(rb->semaphore_rb);
    }

    heap_caps_free(rb);
    rb = NULL;
    return ESP_OK;
}
static ringbuf_handle_t rb_create(uint32_t size)
{
    if (size < (BUFFER_MIN_SIZE << 2)) {
        ESP_LOGE(TAG, "Invalid buffer size, Minimum = %d", (int32_t)(BUFFER_MIN_SIZE << 2));
        return NULL;
    }

    ringbuf_handle_t rb = NULL;
    char *buf = NULL;

    do {
        bool _success =
            (
                (rb             = (ringbuf_handle_t)heap_caps_malloc(sizeof(ringBuf), MALLOC_CAP_8BIT | MALLOC_CAP_INTERNAL)) &&
                (buf            = (char*)heap_caps_malloc(size, MALLOC_CAP_8BIT | MALLOC_CAP_INTERNAL))   &&
                (rb->semaphore_rb   = xSemaphoreCreateBinary())

            );

        if (!_success) {
            break;
        }

        rb->is_give = 0;
        rb->buf = buf;
        rb->head = rb->tail = 0;
        rb->size = size;
        return rb;

    } while (0);

    rb_destroy(rb);
    return NULL;
}

static uint32_t IRAM_ATTR rb_get_count(ringbuf_handle_t rb)
{
    uint32_t tail = rb->tail;

    if (rb->head >= tail) {
        return (rb->head - tail);
    }

    return (rb->size - (tail - rb->head));
}

static uint32_t IRAM_ATTR rb_get_free(ringbuf_handle_t rb)
{
    /** < Free a byte to judge the ringbuffer direction */
    return (rb->size - rb_get_count(rb) - 1);
}

static esp_err_t rb_flush(ringbuf_handle_t rb)
{
    rb->tail = rb->head = 0;
    return ESP_OK;
}

static esp_err_t IRAM_ATTR rb_read_byte(ringbuf_handle_t rb, uint8_t *outdata)
{
    uint32_t tail = rb->tail;

    if (tail == rb->head) {
        return ESP_FAIL;
    }

    // Send a byte from the buffer
    *outdata = rb->buf[tail];

    // Update tail position
    tail++;

    if (tail == rb->size) {
        tail = 0;
    }

    rb->tail = tail;
    return ESP_OK;
}
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
